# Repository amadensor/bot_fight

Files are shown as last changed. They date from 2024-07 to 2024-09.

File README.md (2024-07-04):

#  How to use the system:

*  The network name and password are in the [net_config.txt](timer_code/core_processor/net_config.txt) file.
*  The IP address to point your browser to is displayed as the system boots, assuming a display is attached.
*  The web connection is http, not https.
*  Changes to configuration can be done by editing the [timer_config.txt](timer_code/core_processor/timer_config.txt) configuration file, or by using the web interface.
*  The changes made via web also are saved and will persist after a power cycle.
*  Each cable must connect an A outlet to a B outlet.
   *  This is to accomodate the TX/RX crossover
*  There should be 1 A port and 1 B port left disconnected when complete.
   *  This is because all messages are forwarded, and it would create an infinite loop.
*  The order of modules is gererally unimportant, but the 5VDC should only be injected at one point.
*  The core processor is a Pi Pico W.   All other modules can be normal Pico microcontrollers.

#  Technical details

*  Each module has a Pi Pico in it.  The wiring details are in the [pin_connection.html](pin_connection.html) file.
*  The entire system runs on a message bususing UART over CAT-5.
*  This is using the microdot and utemplate frameworks for simpler web serving and easier maintenance.
*  As this is all Micropython, very little effort would be required (changing pin numbers) to port this to other microcontrollers.

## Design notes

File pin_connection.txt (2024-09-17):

Common:

Blue - VCC 4\
Brown - GND 7\
RXa, TXb - 1\
TXa, RXb - 2

  Use    GPIO#   Pico   RJ-45A   RJ-45B
  ------ ------- ------ -------- --------
  5VDC   VSYS    39     4        4
  GND    GND     38     7        7
  TXa    0       1      1        
  RXa    1       2      2        
  TXb    4       6               2
  RXb    5       7               1

Marshal buttons:

  Use                GPIO#       Pico
  ------------------ ----------- ------
  3.3v for buttons   3.3V(OUT)   36
  start              15          20
  countdown          14          19
  reset              13          17
  config             12          16
  stop               11          15
  ready light        10          14

Small display:

  Use   GPIO#       Pico
  ----- ----------- ------
  DIO   21          27
  CLK   20          26
  GND   GND         28
  VCC   3.3V(OUT)   36

Large display:

  Use     GPIO#   Pico
  ------- ------- ------
  SER     21      27
  CLK     20      26
  LATCH   19      25
  GND     GND     28

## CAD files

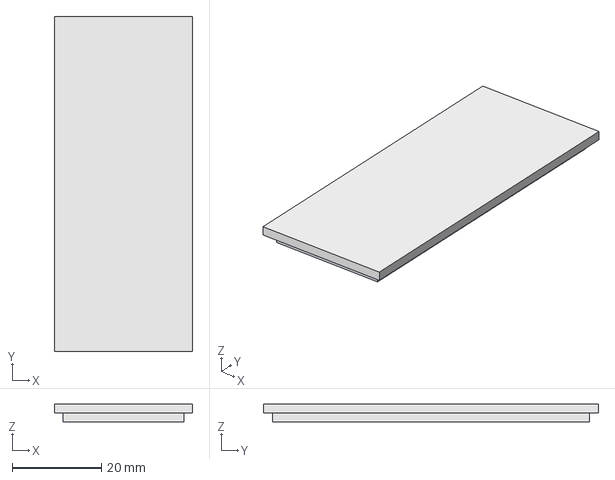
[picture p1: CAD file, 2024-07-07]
cad/small_boxes.FCStd
31.0 x 75.0 x 4.00 mm

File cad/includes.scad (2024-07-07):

$fn=100;
button_hole=29;
button_gap=10;
led_hole=5.5;
box_height=70;
box_depth=100;
box_thickness=2;
port_height=20;
port_width=15;

button_width=((button_hole+button_gap)*5);
module top_plate(){square([box_depth,button_width]);}

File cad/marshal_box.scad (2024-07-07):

include<includes.scad>
  
difference(){
difference()
{
    linear_extrude(box_height)
offset(box_thickness)
top_plate();
   translate([0,0,box_thickness])
linear_extrude(box_height)
top_plate();
}
{
translate([box_depth-5,(button_width/2)-port_width,(box_height)-(port_height)])
rotate([0,90,0])
{
    linear_extrude(20)
    {translate([0,port_height+5,0])
    square([port_height,port_width]);
    square([port_height,port_width]);}
}
}}

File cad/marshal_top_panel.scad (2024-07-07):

include<includes.scad>

linear_extrude(box_thickness)
difference(){
    {offset(box_thickness)
    top_plate();}
    top_plate();}
    
linear_extrude(box_thickness+2)
difference(){
top_plate();
    union(){
        translate([50,(button_hole+button_gap)*.5,0])
        circle(d=button_hole);
        translate([50,(button_hole+button_gap)*1.5,0])
        circle(d=button_hole);
        translate([50,(button_hole+button_gap)*2.5,0])
        circle(d=button_hole);
        translate([50,(button_hole+button_gap)*3.5,0])
        circle(d=button_hole);
        translate([50,(button_hole+button_gap)*4.5,0])
        circle(d=button_hole);
        translate([85,(button_hole+button_gap)*4.5,0])
        circle(d=led_hole);
        }
}

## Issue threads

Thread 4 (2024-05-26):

Bracket builder

amadensor, 2024-05-26:
Import list of competitors
Define rules for match type
  *  Time limit
  * Pit open time
  * Pin timer duration

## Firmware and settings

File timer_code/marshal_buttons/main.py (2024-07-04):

import time
import functions
import machine

start_pin_num=15
countdown_pin_num=14
reset_pin_num=13
config_pin_num=12
stop_pin_num=11
ready_light=machine.Pin(machine.Pin(10),machine.Pin.OUT)

action=None
msg_bus=functions.Bus()

ready_light.off()

start_pin=machine.Pin(start_pin_num,machine.Pin.IN, machine.Pin.PULL_DOWN)
countdown_pin=machine.Pin(countdown_pin_num,machine.Pin.IN, machine.Pin.PULL_DOWN)
reset_pin=machine.Pin(reset_pin_num,machine.Pin.IN, machine.Pin.PULL_DOWN)
config_pin=machine.Pin(config_pin_num,machine.Pin.IN, machine.Pin.PULL_DOWN)
stop_pin=machine.Pin(stop_pin_num,machine.Pin.IN, machine.Pin.PULL_DOWN)

def hardware_loop():
    global action
    if start_pin.value():
        action="start"
    if countdown_pin.value():
        action="countdown"
    if reset_pin.value():
        action="reset"
    if config_pin.value():
        action="config"
    if stop_pin.value():
        action="stop"
    if action:
        message={"button":action}
        msg_bus.send_message(message)
        time.sleep(.25)
        action=None
    msg=msg_bus.handler()
    if msg:
        ready_light.on()

while True:
    hardware_loop()

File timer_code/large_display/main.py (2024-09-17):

import functions
import display_driver

msg_bus=functions.Bus()
display=display_driver.Large_display()
connected=False

def display_time(seconds):
    minutes=seconds//60
    remain=seconds%60
    display_val=(minutes*100)+remain
    display.display_number(display_val)
    
def main():
    global connected
    while True:
        if not connected:
            display.display_number(888)
        msg=msg_bus.handler()
        if msg:
            connected=True
            disp_time=msg.get('display_time')
            if disp_time:
                try:
                    display_time(disp_time)
                except:
                    pass
main()

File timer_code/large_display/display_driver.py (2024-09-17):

import time
import machine

class Large_display:
    def __init__(self, latch=19, clock=20, serial=21, delay=1000):
        self.latch=machine.Pin(latch,machine.Pin.OUT)
        self.clock=machine.Pin(clock, machine.Pin.OUT)
        self.serial=machine.Pin(serial,machine.Pin.OUT)
        self.delay=delay
        a=1<<0 
        c=1<<5
        b=1<<6
        d=1<<4
        e=1<<3
        f=1<<1
        g=1<<2
        dp=1<<7
        self.patterns=[
            a + b + c + d + e + f,
            b + c,
            a + b + d + e + g,
            a + b + c + d + g,
            f + g + b + c,
            a + f + g + c + d,
            a + f + g + e + c + d,
            a + b + c,
            a + b + c + d + e + f + g,
            a + b + c + d + f + g
        ]

    def display_number(self,display_number):
        self.clock.off()
        self.latch.off()
        display_bytes=[]
        while display_number:
            display_digit=display_number%10
            display_number=display_number//10
            display_bytes.append(self.patterns[display_digit])
        while (len(display_bytes) < 4):
            display_bytes.append(0)
        for i in range(4):
            byte=display_bytes[i]
            for t in range(8):
                bit=byte & 1 << (7-t)
                self.clock.off()
                time.sleep_us(self.delay)
                if bit:
                    self.serial.on()
                else:
                    self.serial.off()
                time.sleep_us(self.delay)
                self.clock.on()
                time.sleep_us(self.delay)
        self.latch.off()
        time.sleep_us(self.delay)
        self.latch.on()
        time.sleep_us(self.delay)

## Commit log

2024-06-01 Timer counting up to stdout
2024-06-01 Clean up base timer unit
2024-06-02 Use the nifty display Show current state on the home page
2024-06-05 Add marshall buttons
    [marshal_config.txt]
2024-06-05 Include the more files
    [timer_config.txt]
2024-06-11 Auto config timer URL
    [marshal_config.txt]
2024-06-26 Fix countdown mode Display the ocnfig number
    [main.py]
2024-06-26 Rename the timer display so I can split the core from the display
    [timer_config.txt]
2024-06-26 Start moving to message bus
    [marshal_config.txt]
2024-06-28 Buttons over UART msg bus
2024-07-02 Move display to better pin
2024-07-04 Add net config file
    [net_config.txt]
2024-07-07 Added CAD for marshal button box and small boxes for the display and core
    [includes.scad, marshal_box.scad, marshal_top_panel.scad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]
2024-07-13 Add pin outs for large display
2024-07-14 Catch unicode errors also
    [functions.py]
2024-09-07 Working large display drivery
2024-09-09 New display driver
2024-09-09 Fix deploy script for large display Fix pin numbers on RJ 45 common
2025-08-09 Rip out web stuff to see if it is power issues
    [net_config.txt]
